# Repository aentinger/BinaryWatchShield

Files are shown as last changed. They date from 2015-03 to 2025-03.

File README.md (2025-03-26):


💾 Binary Watch Shield
======================



# 📸 Image

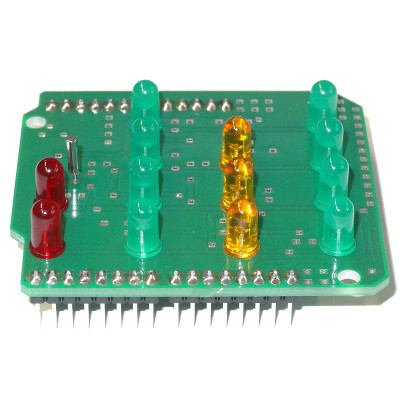
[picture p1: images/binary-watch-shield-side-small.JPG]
LXRobotics P15 BinaryWatchShield


# 📂 Description

There are only 10 types of people in the world: those who understand binary, and those who don't (haha ;P). If you are among the people who do not understand this computer joke, then the LXRobotics Binary Watch Shield is just the thing for you. In conjunction with an Arduino, the Binary Watch Shield may in fact be used to display the current time in binary format. Thereby, learning binary code will become a child's play. For the quick start, a finished Arduino Library with a binary clock sample program is available.

**Features**

* Display of the current time (HH:MM) in binary format using red, orange and green LEDs
* I2C-Real Time Clock  (RTC) for the watch functionality
* Arduino Library available for control with binary clock example programms

# 🎥 [Video](images/binary_watch_shield_demo.mp4)

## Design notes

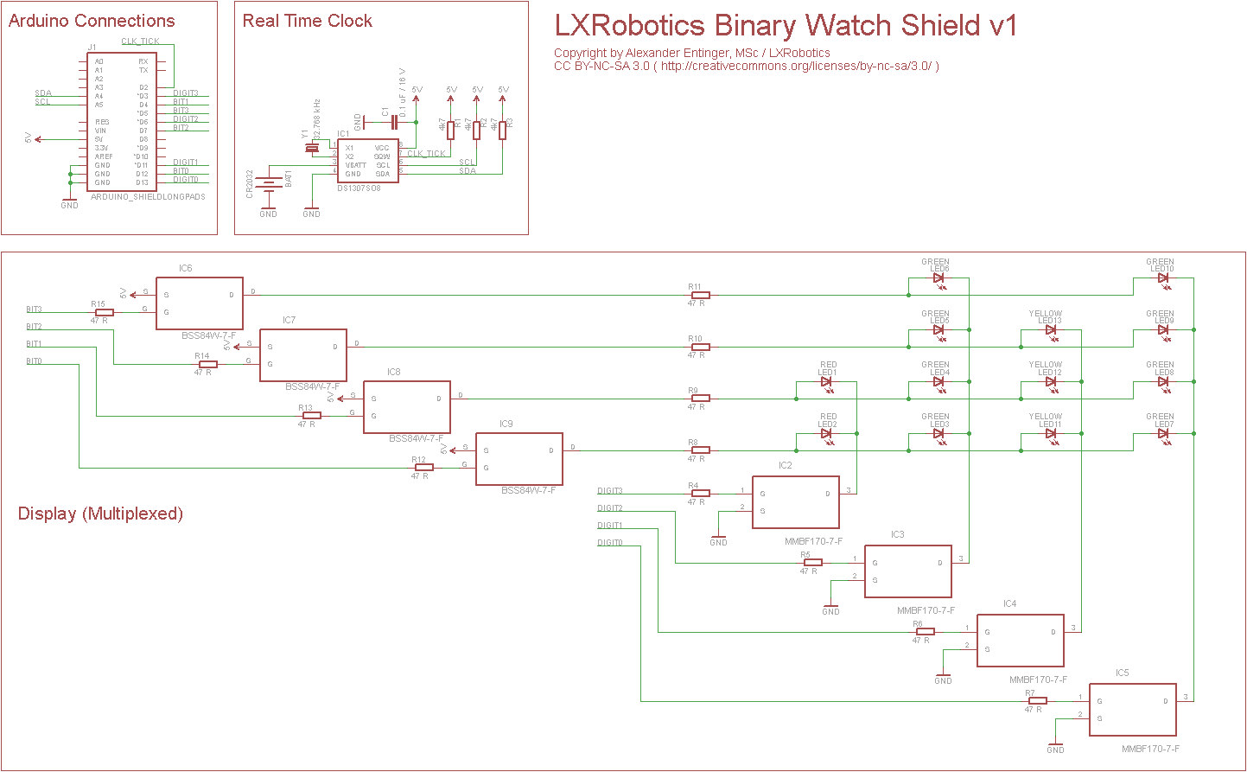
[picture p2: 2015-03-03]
hardware/lxr_binary_watch_shield_v1.png

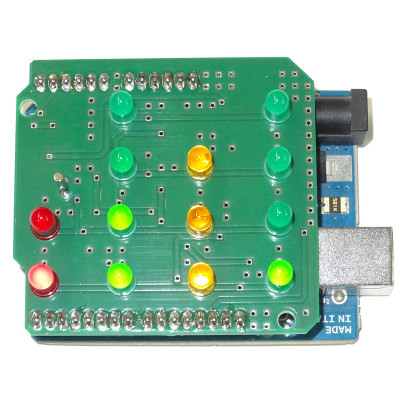
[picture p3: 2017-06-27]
images/binary-watch-shield-action-small.JPG

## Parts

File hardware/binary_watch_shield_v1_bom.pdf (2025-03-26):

Menge | Schaltplan | Bezeichnung | Farnell Bestell Nummer | Preis (1 Stück) | Gesamtpreis | Wird bestückt | Footprint | Säckchen
3 | R1,R2,R3 | Widerstand, 4k7, 0805 | 1469923 | € 0,02 | € 0,06 | X
1 | Y1 | 32,768 kHz Oszillator, R26 | 1652573 | € 0,17 | € 0,17 | | | S1
1 | IC1 | DS1307, SOIC8, I2C RTC | 9725253 | € 4,13 | € 4,13 | X
1 | C1 | 100 nF, 16 V, 0805, Keramikkondensator | 1759144 | € 0,01 | € 0,01 | X
2 | LED1,LED2 | LED Rot, 5 mm, 10 mA, 1.9 V | 1003211 | € 0,19 | € 0,38 | | | S3
8 | LED3-LED10 | LED Grün, 5 mm, 10 mA, 2.1 V | 1003214 | € 0,20 | € 1,58 | | | S3
3 | LED11-LED13 | LED Gelb, 5 mm, 10 mA, 2 V | 1003217 | € 0,15 | € 0,45 | | | S3
4 | IC2-IC5 | MOSFET N KANAL,60V,0.5A,SOT23 | 1773582 | € 0,07 | € 0,26 | X
12 | R1-R15 | Widerstand, 47 R, 0805 | 9334564 | € 0,01 | € 0,06 | X
4 | IC6-IC9 | BSS84W-7-F - MOSFET P-KANAL | 1713836 | € 0,11 | € 0,42 | X
1 | BAT1 | CR2023 Halterung, SMD, RENATA SMTM2032 | 614-SMTM2032 | € | 0,48 | € | 0,48 | X | http://www.mouser.at/ProductDetail/Renata/SMTM2032/?qs=sGAEpiMZZMtT9MhkajLHrup%252bv7eEbxuYhzl6%252bloi5RQ%3d
2 | J1 | Stiftleiste, 2.54 mm, für Verbindung mit Arduino, 8 polig | 1022257 | € 0,19 | € 0,38 | S2
2 | J1 | Stiftleiste, 2.54 mm, für Verbindung mit Arduino, 6 polig | 1022255 | € 0,37 | € 0,74 | S2
Summe | € | 9,14

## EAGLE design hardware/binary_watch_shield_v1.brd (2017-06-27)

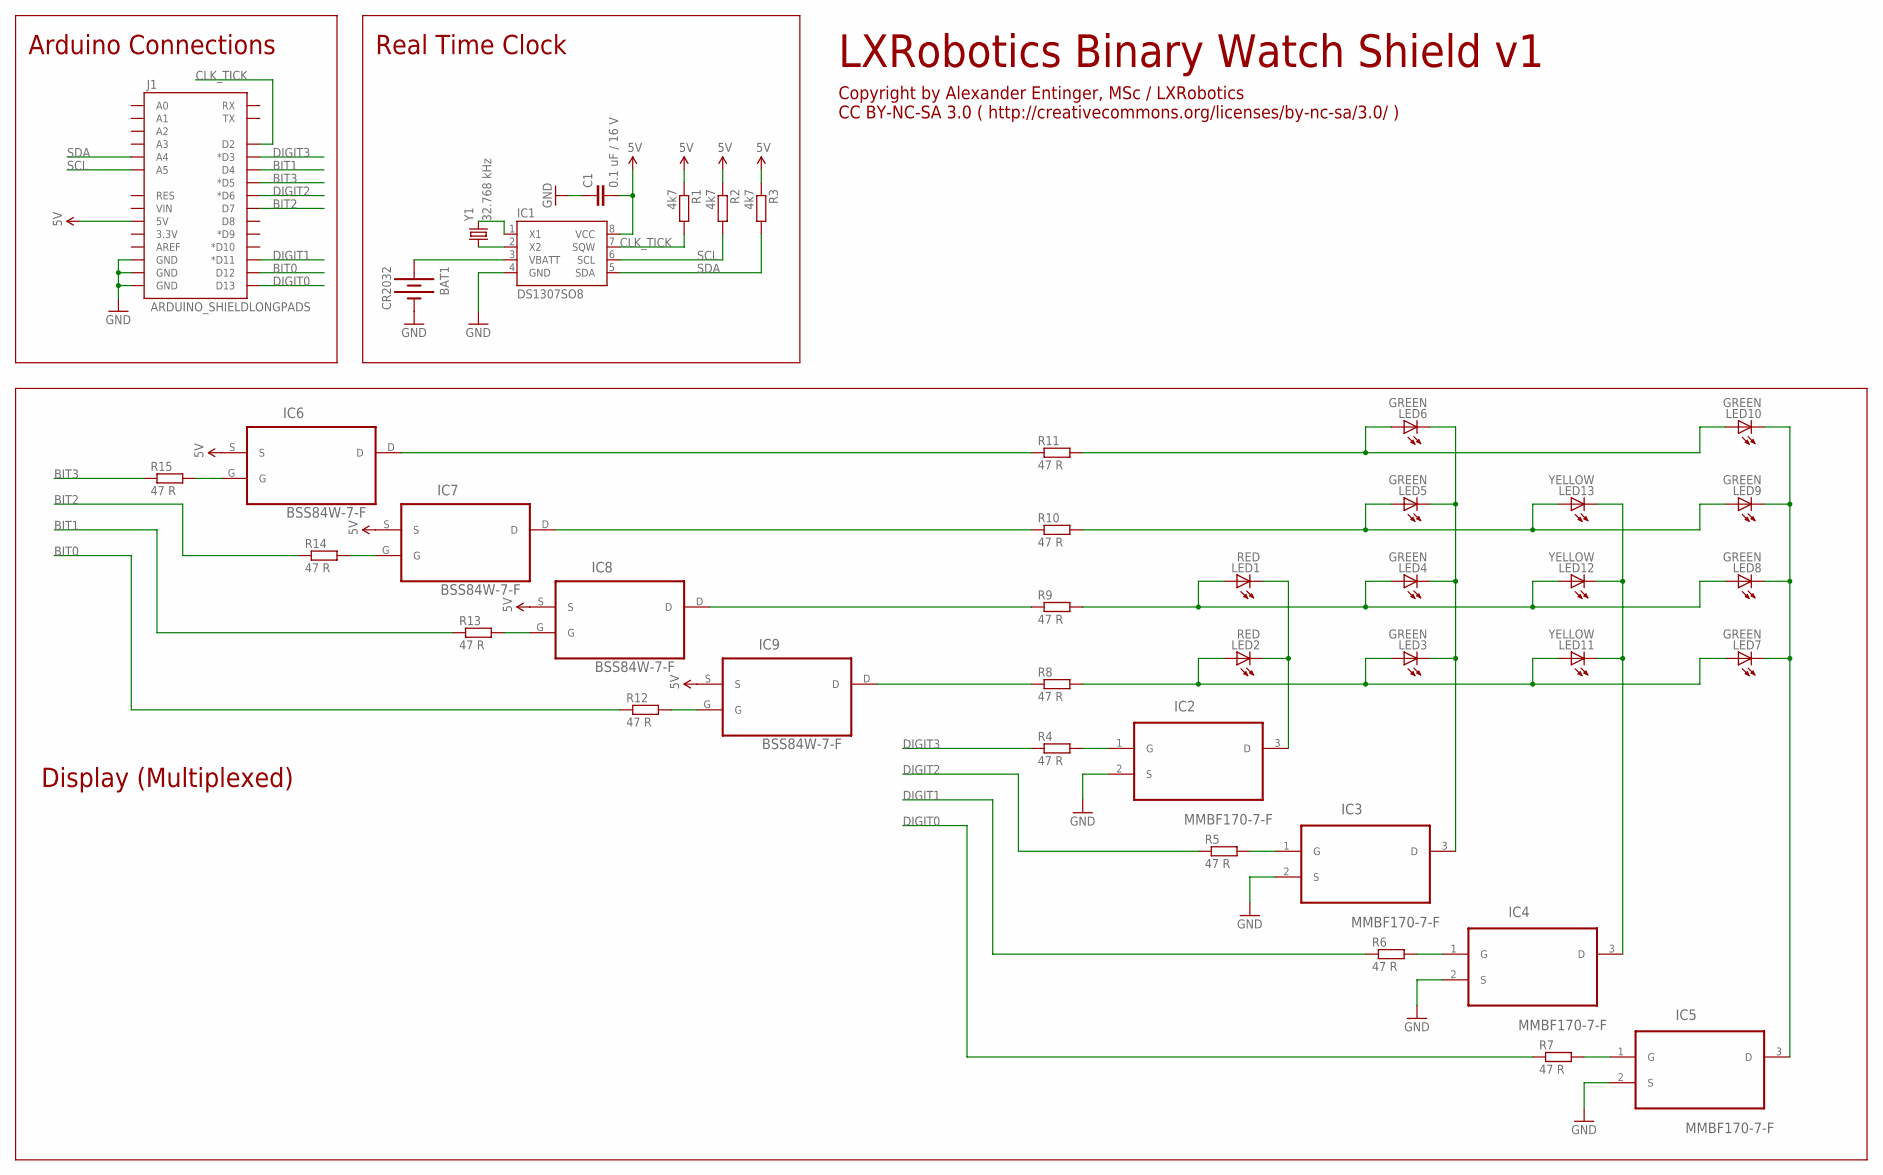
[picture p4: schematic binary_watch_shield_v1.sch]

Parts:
BAT1: CR2032; BATTCON_20MM
C1: 0.1 uF / 16 V; C0805
IC1: DS1307SO8; SO08
IC2, IC3, IC4, IC5: MMBF170-7-F; SOT103P240X110-3N
IC6, IC7, IC8, IC9: BSS84W-7-F; SOT65P210X110-3N
J1: ARDUINO_SHIELDLONGPADS; DUEMILANOVE_SHIELD_LONGPADS
LED1, LED2: RED; LED5MM
LED3, LED4, LED5, LED6, LED7, LED8, LED9, LED10: GREEN; LED5MM
LED11, LED12, LED13: YELLOW; LED5MM
R1, R2, R3: 4k7; R0805
R4, R5, R6, R7, R8, R9, R10, R11, R12, R13, R14, R15: 47 R; R0805
Y1: 32.768 kHz; TC26HEZ

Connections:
5V: C1.2, IC1.8 (VCC), IC6.S, IC7.S, IC8.S, IC9.S, J1.5V, R1.1, R2.1, R3.1
BIT0: J1.D12, R12.1
BIT1: J1.D4, R13.1
BIT2: J1.D7, R14.1
BIT3: J1.D5 (*D5), R15.1
CLK_TICK: IC1.7 (SQW), J1.D2, R1.2
DIGIT0: J1.D13, R7.1
DIGIT1: J1.D11 (*D11), R6.1
DIGIT2: J1.D6 (*D6), R5.1
DIGIT3: J1.D3 (*D3), R4.1
GND: BAT1.2 (-), C1.1, IC1.4 (GND), IC2.2 (S), IC3.2 (S), IC4.2 (S), IC5.2 (S), J1.GND@0 (GND), J1.GND@1 (GND), J1.GND@2 (GND)
unnamed: IC2.3 (D), LED1.K (C), LED2.K (C)
unnamed: IC3.3 (D), LED3.K (C), LED4.K (C), LED5.K (C), LED6.K (C)
unnamed: IC4.3 (D), LED11.K (C), LED12.K (C), LED13.K (C)
unnamed: IC1.2 (X2), Y1.1
unnamed: IC1.1 (X1), Y1.2
unnamed: IC5.3 (D), LED7.K (C), LED8.K (C), LED9.K (C), LED10.K (C)
unnamed: LED5.A, LED9.A, LED13.A, R10.2
unnamed: LED2.A, LED3.A, LED7.A, LED11.A, R8.2
unnamed: LED1.A, LED4.A, LED8.A, LED12.A, R9.2
unnamed: LED6.A, LED10.A, R11.2
unnamed: IC2.1 (G), R4.2
unnamed: IC3.1 (G), R5.2
unnamed: IC4.1 (G), R6.2
unnamed: IC5.1 (G), R7.2
unnamed: IC9.D, R8.1
unnamed: IC8.D, R9.1
unnamed: IC7.D, R10.1
unnamed: IC6.D, R11.1
unnamed: IC6.G, R15.2
unnamed: IC7.G, R14.2
unnamed: IC8.G, R13.2
unnamed: IC9.G, R12.2
unnamed: BAT1.1 (+), IC1.3 (VBATT)
SCL: IC1.6 (SCL), J1.A5, R2.2
SDA: IC1.5 (SDA), J1.A4, R3.2

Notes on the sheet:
Copyright by Alexander Entinger, MSc / LXRobotics CC BY-NC-SA 3.0 ( http://creativecommons.org/licenses/by-nc-sa/3.0/ )
LXRobotics Binary Watch Shield v1
Arduino Connections
Real Time Clock
Display (Multiplexed)

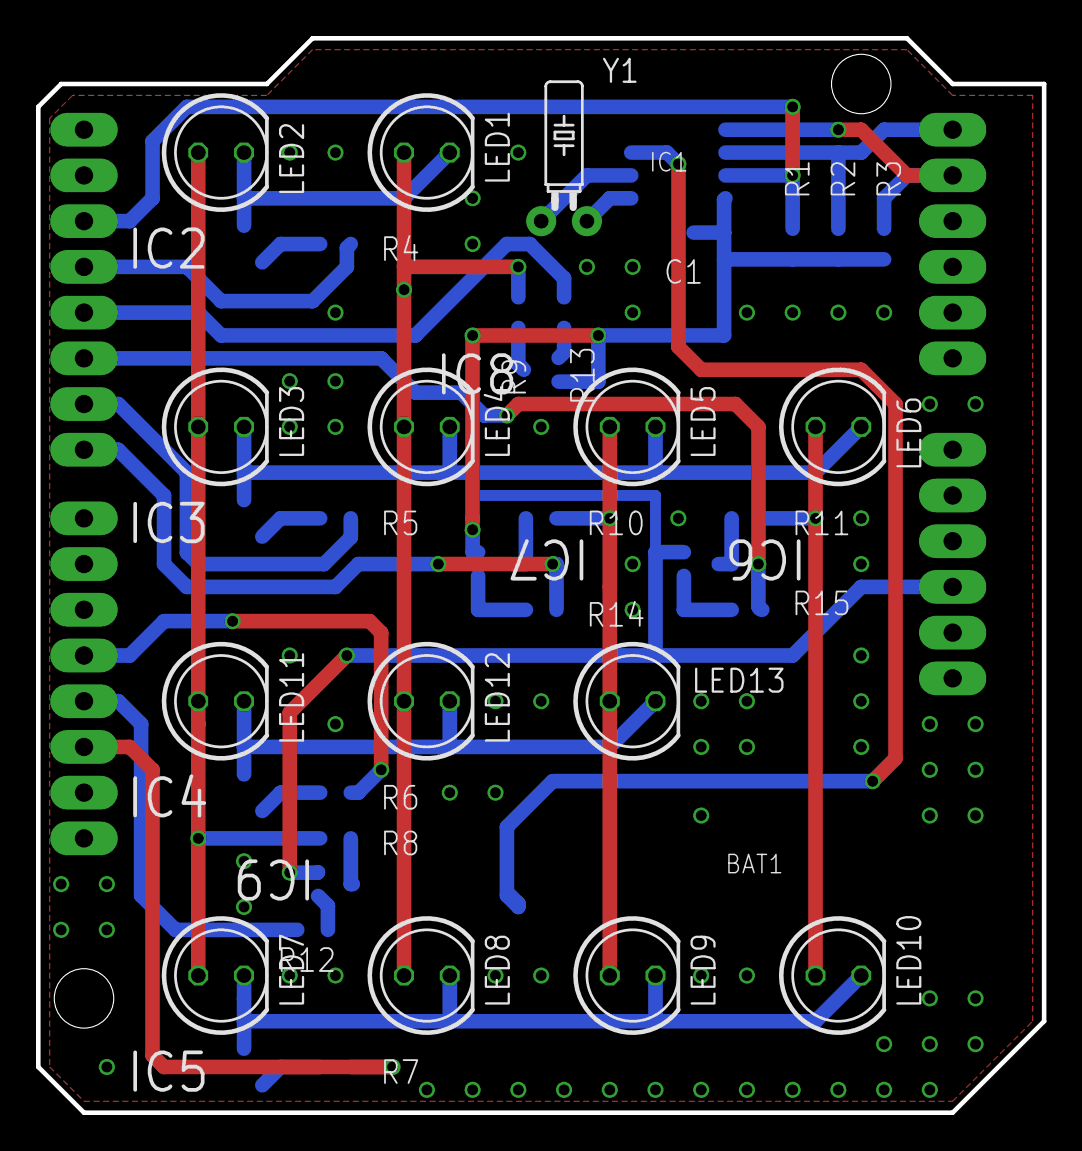
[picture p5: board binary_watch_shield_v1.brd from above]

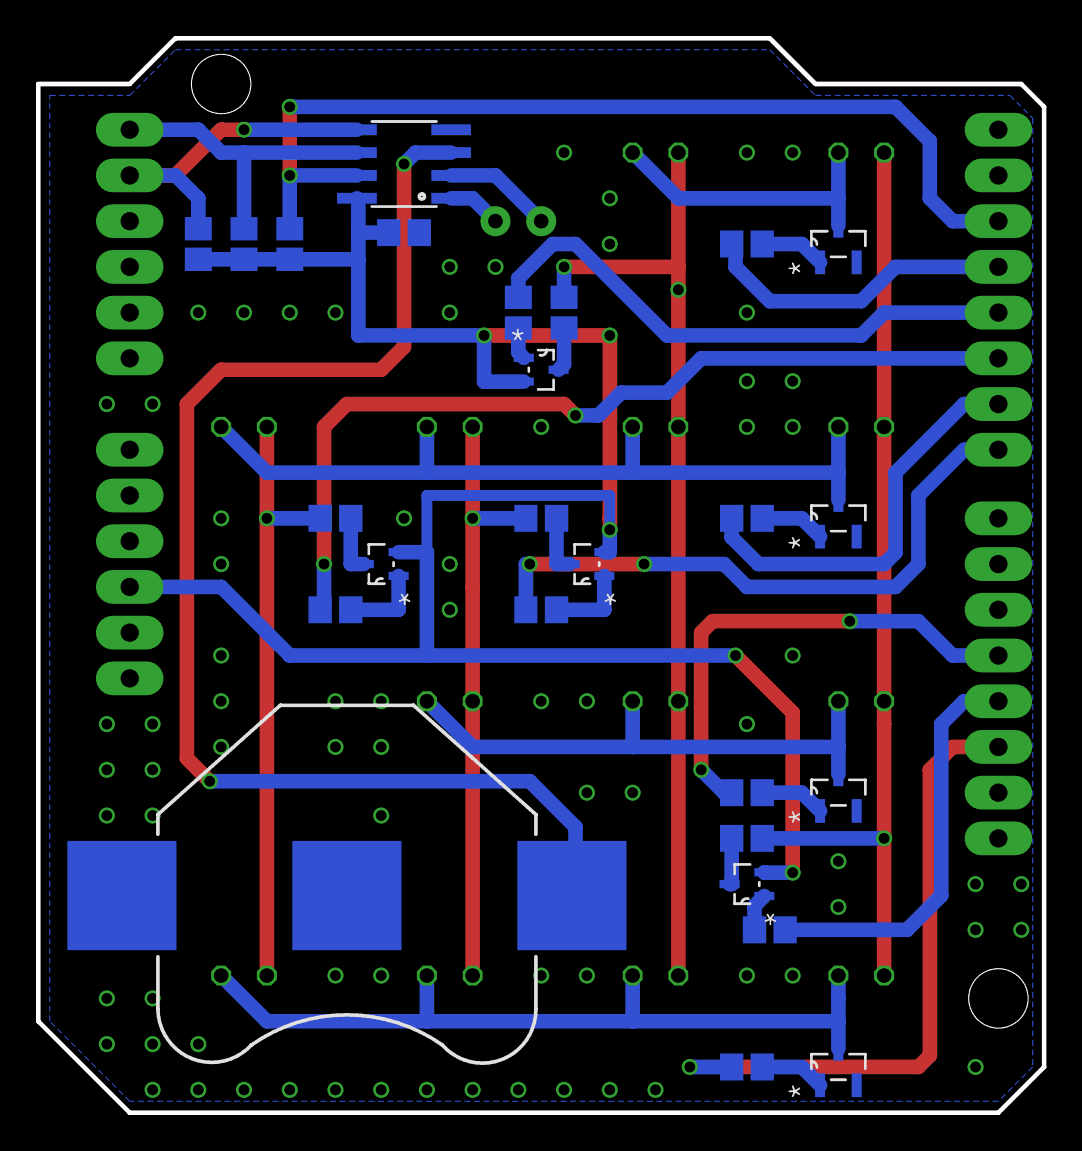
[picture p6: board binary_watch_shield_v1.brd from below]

Board: 2 copper layers, 55.9 x 59.7 mm, 41 parts (26 on the bottom side), 36 nets.

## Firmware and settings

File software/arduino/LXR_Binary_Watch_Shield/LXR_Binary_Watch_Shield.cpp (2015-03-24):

/**
 * @author Alexander Entinger, MSc / LXRobotics
 * @brief this module implements the library for controlling the LXRobotics Binary Watch Shield
 * @file LXR_Binary_Watch_Shield.cpp
 * @license Attribution-NonCommercial-ShareAlike 3.0 Unported (CC BY-NC-SA 4.0) ( https://creativecommons.org/licenses/by-nc-sa/4.0/ )
 */
 
#include "LXR_Binary_Watch_Shield.h"

/* C CODE */

/* INCLUDES */

#include <avr/io.h>
#include <avr/interrupt.h>

/* DEFINES */

// DIGIT0 = D13 = PB5
#define DIGIT_0_DDR		(DDRB)
#define DIGIT_0_PORT	(PORTB)
#define DIGIT_0_bm		(1<<PORTB5)
// DIGIT1 = D11 = PB3
#define DIGIT_1_DDR		(DDRB)
#define DIGIT_1_PORT	(PORTB)
#define DIGIT_1_bm		(1<<PORTB3)
// DIGIT2 = D6 = PD6
#define DIGIT_2_DDR		(DDRD)
#define DIGIT_2_PORT	(PORTD)
#define DIGIT_2_bm		(1<<PORTD6)
// DIGIT3 = D3 = PD3
#define DIGIT_3_DDR		(DDRD)
#define DIGIT_3_PORT	(PORTD)
#define DIGIT_3_bm		(1<<PORTD3)
// BIT0 = D12 = PB4
#define BIT_0_DDR		(DDRB)
#define BIT_0_PORT		(PORTB)
#define BIT_0_bm		(1<<PORTB4)
// BIT1 = D4 = PD4
#define BIT_1_DDR		(DDRD)
#define BIT_1_PORT		(PORTD)
#define BIT_1_bm		(1<<PORTD4)
// BIT2 = D7 = PD7
#define BIT_2_DDR		(DDRD)
#define BIT_2_PORT		(PORTD)
#define BIT_2_bm		(1<<PORTD7)
// BIT3 = D5 = PD5
#define BIT_3_DDR		(DDRD)
#define BIT_3_PORT		(PORTD)
#define BIT_3_bm		(1<<PORTD5)

/* TYPEDEFS */

typedef enum {DIGIT0 = 0, DIGIT1 = 1, DIGIT2 = 2, DIGIT3 = 3} E_DIGIT_SELECT;

typedef struct 
{
	uint8_t current_digit;
	uint8_t display_data[4];
} s_binary_watch_shield_data; 

/* GLOBAL CONSTANTS */

static uint16_t const TIMER1_RELOAD_VALUE = 0xC180;

/* GLOBAL VARIABLES */

static s_binary_watch_shield_data bws_data = {0};

/* PROTOTYPES */

void set_digit(E_DIGIT_SELECT const digit, uint8_t const val);

/* FUNCTIONS */

/** 
 * @brief initializes the binary watch shield
 */
void init_binary_watch_shield()
{
	// set all pins as outputs
	DIGIT_0_DDR |= DIGIT_0_bm;
	DIGIT_1_DDR |= DIGIT_1_bm;
	DIGIT_2_DDR |= DIGIT_2_bm;
	DIGIT_3_DDR |= DIGIT_3_bm;
	
	BIT_0_DDR |= BIT_0_bm;
	BIT_1_DDR |= BIT_1_bm;
	BIT_2_DDR |= BIT_2_bm;
	BIT_3_DDR |= BIT_3_bm;
	
	// set up timer 1
	// fclk = 16 MHz, prescaler = 1, fTimer = 16 MHz, tTimer = 62.5 ns
	// tUpdate,Period = 1 ms -> 16000 Timersteps
	// Reload-Wert = 65536 - 16000 = 0xC180
	TCNT1 = TIMER1_RELOAD_VALUE;
	// enable overflow interrupt
	TIMSK1 = (1<<TOIE1);
	// start timer
	TCCR1B = (1<<CS10);	
}

/** 
 * @brief set the numbers for the binary watch shield to display
 */
void binary_watch_shield_set_display(uint8_t const digit_3, uint8_t const digit_2, uint8_t const digit_1, uint8_t const digit_0)
{
	cli();
	bws_data.display_data[DIGIT0] = digit_0;
	bws_data.display_data[DIGIT1] = digit_1;
	bws_data.display_data[DIGIT2] = digit_2;
	bws_data.display_data[DIGIT3] = digit_3;
	sei();
}

void set_digit(E_DIGIT_SELECT const digit, uint8_t const val)
{
	// switch all digits off
	DIGIT_0_PORT &= ~DIGIT_0_bm;
	DIGIT_1_PORT &= ~DIGIT_1_bm;
	DIGIT_2_PORT &= ~DIGIT_2_bm;
	DIGIT_3_PORT &= ~DIGIT_3_bm;
	
	// display value on the bit lines
	uint8_t tmp = val;
	if(tmp % 2) BIT_0_PORT &= ~BIT_0_bm;
	else BIT_0_PORT |= BIT_0_bm;
	tmp /= 2;
	if(tmp % 2) BIT_1_PORT &= ~BIT_1_bm;
	else BIT_1_PORT |= BIT_1_bm;
	tmp /= 2;
	if(tmp % 2) BIT_2_PORT &= ~BIT_2_bm;
	else BIT_2_PORT |= BIT_2_bm;
	tmp /= 2;
	if(tmp % 2) BIT_3_PORT &= ~BIT_3_bm;
	else BIT_3_PORT |= BIT_3_bm;
	
	// switch the selected digit on
	switch(digit)
	{
		case DIGIT0: DIGIT_0_PORT |= DIGIT_0_bm; break;		
		case DIGIT1: DIGIT_1_PORT |= DIGIT_1_bm; break;
		case DIGIT2: DIGIT_2_PORT |= DIGIT_2_bm; break;
		case DIGIT3: DIGIT_3_PORT |= DIGIT_3_bm; break;
		default: break;
	}
}

/** 
 * @brief Interrupt Service Routine for Timer 1 Overflow
 */
ISR(TIMER1_OVF_vect)
{
	// reload timer
	TCNT1 = TIMER1_RELOAD_VALUE;
	
	// set the digit
	set_digit(E_DIGIT_SELECT(bws_data.current_digit), bws_data.display_data[bws_data.current_digit]);
	
	// update current digit state
	bws_data.current_digit = (bws_data.current_digit + 1) % 4;
}

/* CPP WRAPPER */

/** 
 * @brief initializes the library
 */
void LXR_Binary_Watch_Shield::begin()
{
  init_binary_watch_shield();
}
  
/**
 * @brief sets what number should be displayed on which digit of the binary watch shield
 */
void LXR_Binary_Watch_Shield::set_display(uint8_t const digit_3, uint8_t const digit_2, uint8_t const digit_1, uint8_t const digit_0)
{
  binary_watch_shield_set_display(digit_3, digit_2, digit_1, digit_0);
}

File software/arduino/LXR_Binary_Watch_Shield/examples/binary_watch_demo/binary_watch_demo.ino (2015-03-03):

/** 
 * @author Alexander Entinger MSc, LXRobotics
 * @brief this file demonstrates how to use the IV18 library in combination with the LXR Tubeclock shield (+ LXR_Tubeclock_Shield Library)
 * @file binary_watch_demo.ino
 * @license Attribution-NonCommercial-ShareAlike 3.0 Unported (CC BY-NC-SA 3.0) ( http://creativecommons.org/licenses/by-nc-sa/3.0/ )
 */

#include "LXR_Binary_Watch_Shield.h" 
#include <Wire.h> // necessary for RTClib
#include "RTClib.h"

RTC_DS1307 RTC;

void setup() 
{
  // initialize the binary watch shield
  LXR_Binary_Watch_Shield::begin();
  
  // setup the real time clock
  Wire.begin();
  RTC.begin(); 
  RTC.adjust(DateTime(__DATE__, __TIME__)); // sets the RTC to the date & time this sketch was compiled
  RTC.setSqwOutSignal(RTC_DS1307::Frequency_1Hz); // set output frequency to 1 Hz
  RTC.register_callback(&tick, EINT0);
}

static boolean update_display = false;
/**
 * @brief this function is executed once per second
 */
void tick() 
{
  // update flag
  update_display = true;
}


void loop()
{
  if(update_display)
  {
    // update flag
    update_display = false;
  
    // get current time
    DateTime now = RTC.now();
    uint8_t const hour = now.hour();
    uint8_t const minute = now.minute();
    
    // convert to digit representation
    uint8_t const dig_3 = hour / 10;
    uint8_t const dig_2 = hour % 10;
    uint8_t const dig_1 = minute / 10;
    uint8_t const dig_0 = minute % 10; 
 
    // update the display driver
    LXR_Binary_Watch_Shield::set_display(dig_3,dig_2,dig_1,dig_0);   
  }  
}

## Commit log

2015-03-24 bugfix in binary watch shield library
    [LXR_Binary_Watch_Shield.cpp]
2017-06-27 Adding hardware + images
    [binary_watch_shield_v1.brd, binary_watch_shield_v1.sch]
2025-03-26 Add BOM.

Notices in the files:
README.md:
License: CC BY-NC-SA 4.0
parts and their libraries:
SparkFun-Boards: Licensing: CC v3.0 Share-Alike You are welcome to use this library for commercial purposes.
